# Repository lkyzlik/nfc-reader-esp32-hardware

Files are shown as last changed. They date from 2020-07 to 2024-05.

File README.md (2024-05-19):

# NFC Reader ESP32 Hardware
Hardware part of the secure NFC card reader developed on the ESP32 platform. My Bachelor thesis project created at Brno University of Technology.

## Other Parts
* Software part: [github.com/lkyzlik/nfc-reader-esp32-software](https://github.com/lkyzlik/nfc-reader-esp32-software)

## List of Components
| ID | Component | Amount |
|---|---|---|
| BT1 | LiPol battery 1200mAh | 1 |
| C1, C3, C6 | Capacitor 100nF THT | 3 |
| C2, C4 | Capacitor 10μF THT | 2 |
| C5, C7 | Capacitor 100μF THT | 2 |
| D1 | Shottky diode THT | 1 |
| D2 | Red-green LED THT 5mm | 1 |
| J1 | Barrel Jack | 1 |
| J2, J3 | Pin socket 1x15 (for ESP32) | 2 |
| J4 | Pin socket 1x8 (for PN532)  | 1 |
| Q1 | PMOS transistor SMD | 1 |
| R1 | Resistor 2kΩ THT | 1 |
| R2,R3 | Resistor 330Ω THT | 2 |
| R4, R6, R7 | Resistor 4.7kΩ THT | 3 |
| R5 | Resistor 1kΩ THT | 1 |
| U1 | MCP73832 IC SMD | 1 |
| U2 | LF33 IC SMD | 1 |
| | Source DC 5V | 1 |
| | PCB with manufacturing | 1 |
| | [ESP32 DevKit v1](https://docs.zerynth.com/latest/official/board.zerynth.doit_esp32/docs/index.html) | 1 |
| | [PN532 module](https://components101.com/wireless/pn532-nfc-rfid-module) | 1 |

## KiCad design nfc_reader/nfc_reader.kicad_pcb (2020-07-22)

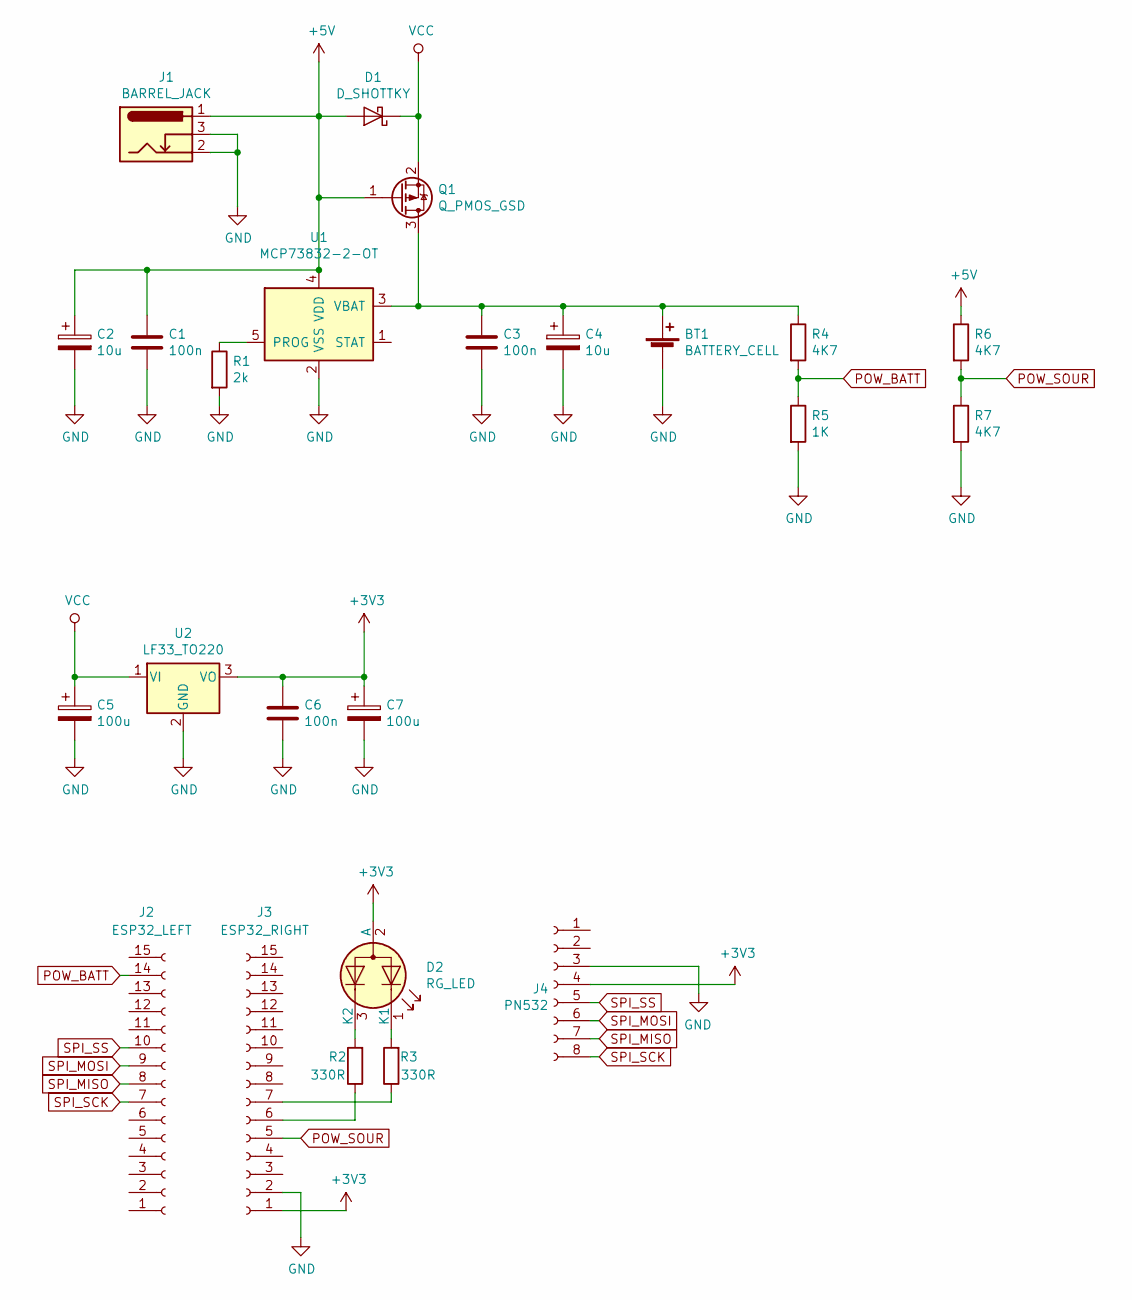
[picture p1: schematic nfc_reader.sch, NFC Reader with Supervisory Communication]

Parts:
BT1: BATTERY_CELL; TestPoint_2Pads_Pitch2.54mm_Drill0.8mm
C1, C3, C6: 100n; C_Disc_D3.0mm_W1.6mm_P2.50mm
C2, C4: 10u; CP_Radial_D6.3mm_P2.50mm
C5, C7: 100u; CP_Radial_D6.3mm_P2.50mm
D1: D_SHOTTKY; D_A-405_P7.62mm_Horizontal
D2: RG_LED; LED_D5.0mm-3
J1: BARREL_JACK; BarrelJack_Horizontal
J2: ESP32_LEFT; PinSocket_1x15_P2.54mm_Vertical
J3: ESP32_RIGHT; PinSocket_1x15_P2.54mm_Vertical
J4: PN532; PinSocket_1x08_P2.54mm_Horizontal
Q1: Q_PMOS_GSD; SOT-23_Handsoldering
R1: 2k; R_Axial_DIN0204_L3.6mm_D1.6mm_P7.62mm_Horizontal
R2, R3: 330R; R_Axial_DIN0204_L3.6mm_D1.6mm_P7.62mm_Horizontal
R4, R6, R7: 4K7; R_Axial_DIN0204_L3.6mm_D1.6mm_P7.62mm_Horizontal
R5: 1K; R_Axial_DIN0204_L3.6mm_D1.6mm_P7.62mm_Horizontal
U1: MCP73832-2-OT; SOT-23-5
U2: LF33_TO220; TO-252-2

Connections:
+3V3: C6.1, C7.1, D2.2 (A), J3.1, J4.4, U2.3 (VO)
+5V: C1.1, C2.1, D1.2 (A), J1.1, Q1.1 (G), R6.1, U1.4 (VDD)
GND: BT1.2 (-), C1.2, C2.2, C3.2, C4.2, C5.2, C6.2, C7.2, J1.2, J1.3, J3.2, J4.3, R1.2, R5.2, R7.2, U1.2 (VSS), U2.2 (GND)
unnamed: BT1.1 (+), C3.1, C4.1, Q1.3 (D), R4.1, U1.3 (VBAT)
unnamed: D2.1 (K1), R3.2
unnamed: D2.3 (K2), R2.2
unnamed: J3.6, R2.1
unnamed: J3.7, R3.1
unnamed: R1.1, U1.5 (PROG)
POW_BATT: J2.14, R4.2, R5.1
POW_SOUR: J3.5, R6.2, R7.1
SPI_MISO: J2.8, J4.7
SPI_MOSI: J2.9, J4.6
SPI_SCK: J2.7, J4.8
SPI_SS: J2.10, J4.5
VCC: C5.1, D1.1 (K), Q1.2 (S), U2.1 (VI)

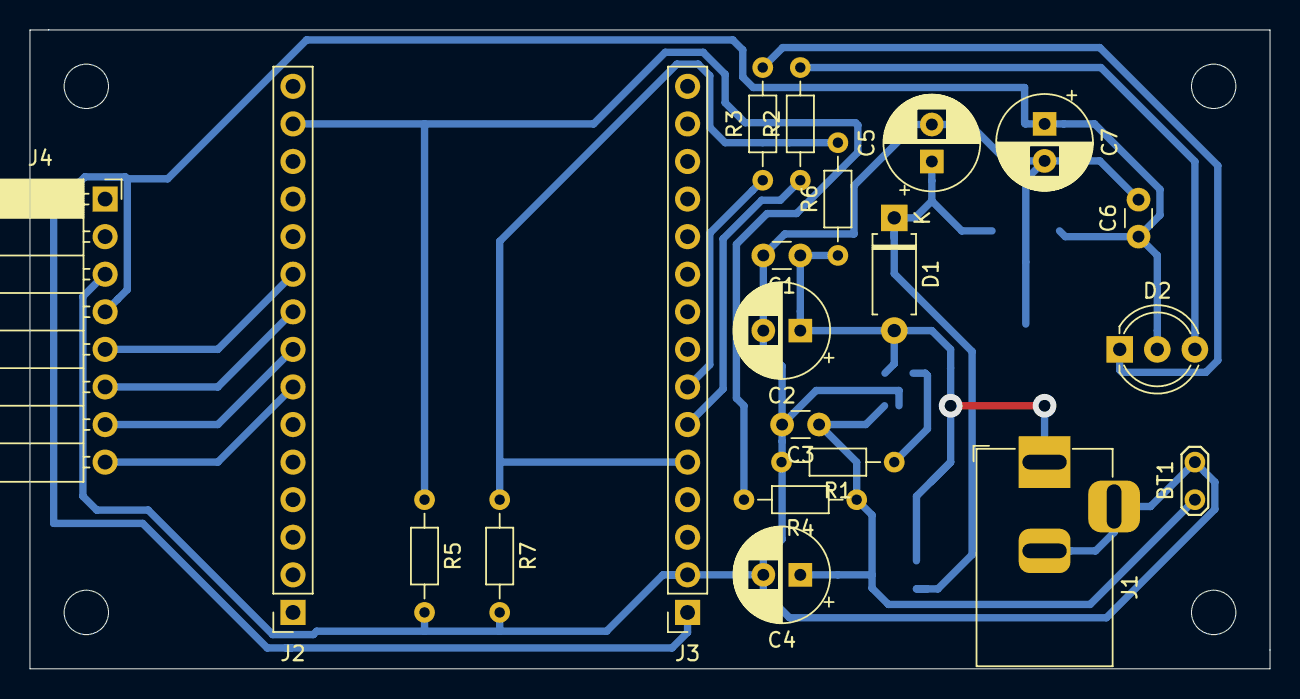
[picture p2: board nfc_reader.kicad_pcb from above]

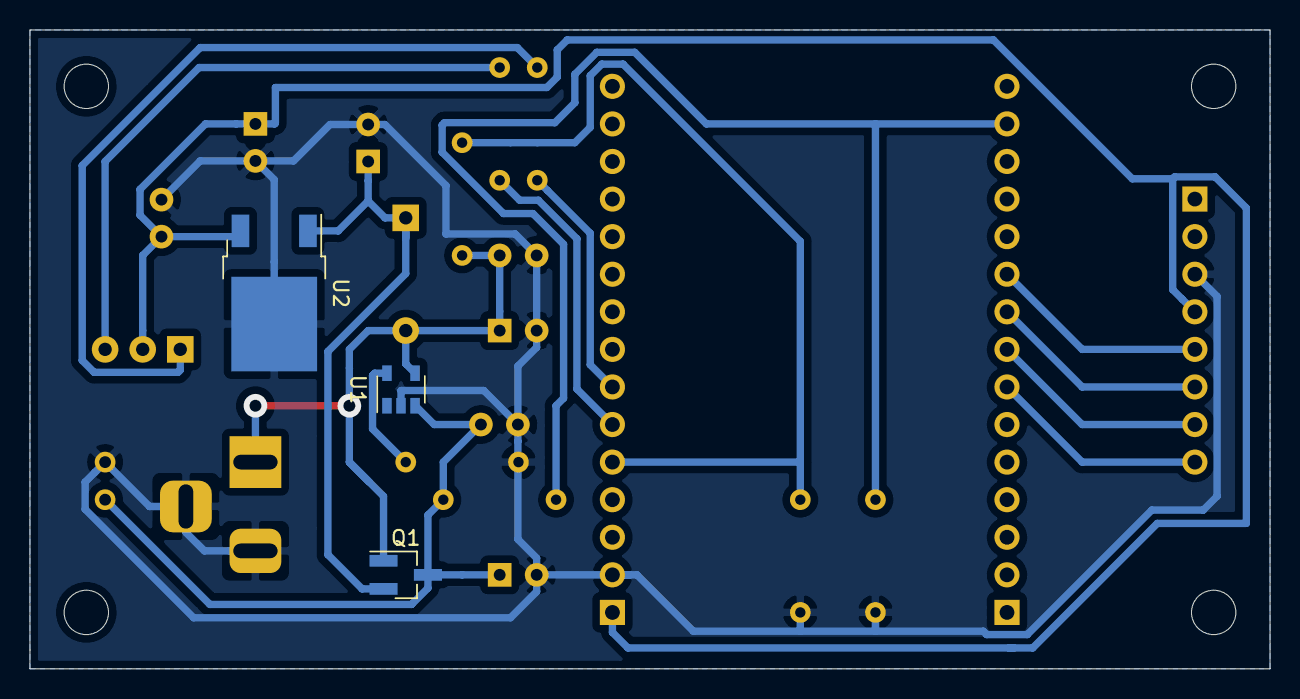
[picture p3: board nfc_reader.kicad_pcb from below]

Board: 2 copper layers, 83.8 x 43.2 mm, 24 parts (3 on the bottom side), 16 nets.

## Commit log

2020-04-14 First draft of the scheme.
    [nfcid_reader.kicad_pcb, nfcid_reader.sch]
2020-04-16 Scheme update. Footprint assignation started.
    [nfcid_reader.sch]
2020-05-01 First draft. Problems to be solved: thick via, bridge.
    [nfcid_reader.sch]
2020-05-02 Fixed thick track, ESP orentation. Added bridge, edge cuts.
    [nfcid_reader.kicad_pcb, nfcid_reader.sch]
2020-05-04 Minor fixes.
    [nfcid_reader.kicad_pcb]
2020-05-04 RC-1: Added votage dividers. J4 fliped.
    [nfcid_reader.kicad_pcb, nfcid_reader.sch]
2020-05-06 RC-2: U2 changed to SMD. LED moved.
    [nfcid_reader.kicad_pcb, nfcid_reader.sch]
2020-05-07 RC-3: Tracks moved to back. SMDs fliped.
    [nfcid_reader.kicad_pcb]
2020-05-22 RC4: Fixed wrong ADC pin connection.
    [nfcid_reader.kicad_pcb, nfcid_reader.sch]
2020-07-22 v1.0: Fixed PN532 polarisation. Updated readme.
    [nfc_reader.kicad_pcb, nfc_reader.sch]
2020-07-22 Deleted obsolite files. New folder.
    [nfc_reader.kicad_pcb, nfc_reader.sch, nfcid_reader.kicad_pcb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]
